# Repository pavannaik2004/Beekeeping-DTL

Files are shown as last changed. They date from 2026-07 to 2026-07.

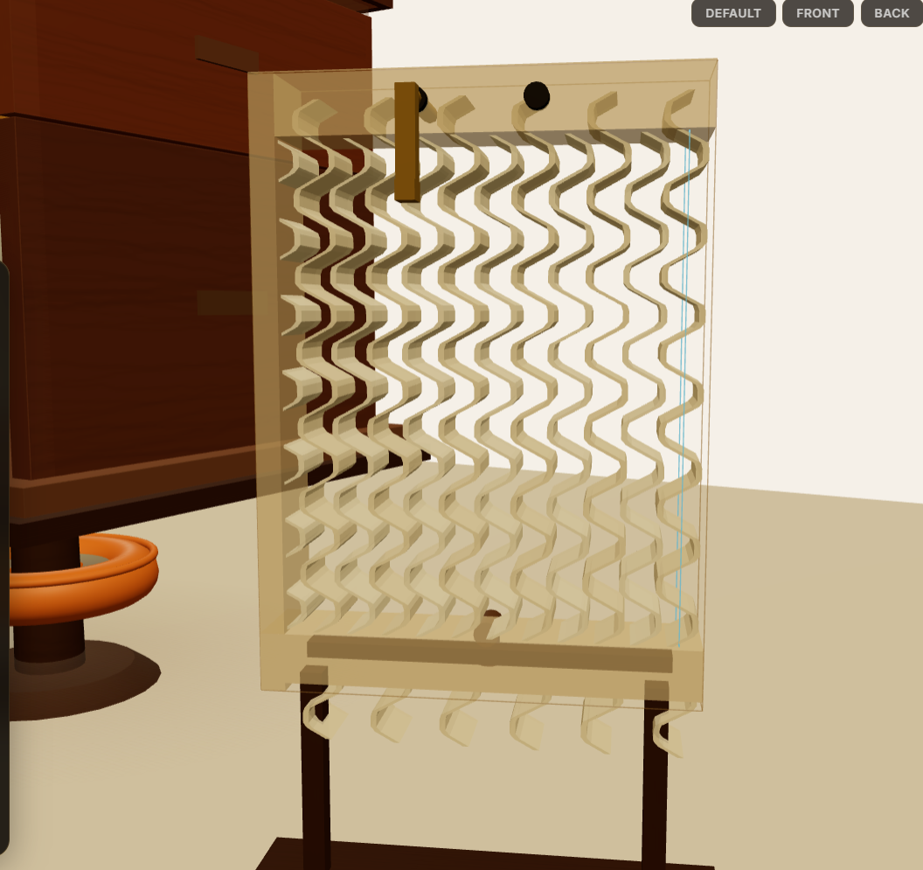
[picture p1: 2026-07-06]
04-prototype/prototype-versions/detailed_flowframe.png

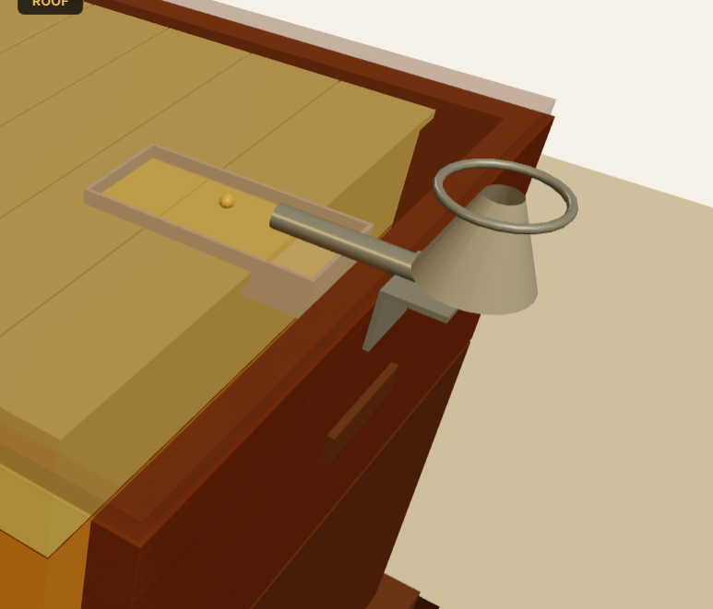
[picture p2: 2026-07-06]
04-prototype/prototype-versions/feeder.png

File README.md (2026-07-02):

# Beekeeping-DTL: Efficient Beekeeping and Hive Box

## File Structure

```text
Directory structure:
└── pavannaik2004-beekeeping-dtl/
    ├── README.md
    ├── 01-empathy/
    │   ├── 00-overview.md
    │   ├── 01-research/
    │   │   ├── context-notes.md
    │   │   ├── field-observation.md
    │   │   ├── FLOW-HIVE-–-A-NOVEL-TECHNOLOGY-FOR-BEEKEEPING.pdf
    │   │   ├── important-links.md
    │   │   ├── is.1515.1998.pdf
    │   │   ├── Promoting Scientific Beekeeping For Livelihood Security.pdf
    │   │   ├── Scientific-Bee-Keeping-Report-2.pdf
    │   │   ├── secondary-research.md
    │   │   └── Media/
    │   │       ├── Bee box.png
    │   │       ├── Beecamp.jpg
    │   │       ├── capped_frame.jpg
    │   │       ├── extra_hive_above_box.jpg
    │   │       ├── frame_after_harvesting.jpg
    │   │       ├── Life-cycle-honeybee.webp
    │   │       ├── pavan_holding_frame.jpg
    │   │       ├── sizes-honeybee-worker-queen-drone.webp
    │   │       └── sumanth_holding_frame.jpg
    │   ├── 02-survey/
    │   │   ├── bee-questionnaire.md
    │   │   ├── survey-design-notes.md
    │   │   └── responses/
    │   │       └── Beekeeping Practices and Challenges Survey  (Responses).xlsx
    │   ├── 03-interviews/
    │   │   ├── interview-index.md
    │   │   ├── Akshay Kedla/
    │   │   │   ├── Akshay Kedla Interview.mp3
    │   │   │   ├── README.md
    │   │   │   ├── summary.md
    │   │   │   └── transcript.md
    │   │   ├── Dhruv Bhat/
    │   │   │   ├── Dhruva Bhat Researcher.mp3
    │   │   │   ├── README.md
    │   │   │   ├── summary.md
    │   │   │   ├── transcript.md
    │   │   │   └── Media/
    │   │   │       ├── WhatsApp Image 2026-05-13 at 16.46.42 (1).jpeg
    │   │   │       ├── WhatsApp Image 2026-05-13 at 16.46.42 (2).jpeg
    │   │   │       ├── WhatsApp Image 2026-05-13 at 16.46.42.jpeg
    │   │   │       ├── WhatsApp Image 2026-05-13 at 16.46.43.jpeg
    │   │   │       ├── WhatsApp Image 2026-05-13 at 16.47.08.jpeg
    │   │   │       ├── WhatsApp Image 2026-05-13 at 16.47.23.jpeg
    │   │   │       ├── WhatsApp Image 2026-05-13 at 16.50.06.jpeg
    │   │   │       └── WhatsApp Video 2026-05-13 at 16.49.09.mp4
    │   │   ├── Harsha Hegde/
    │   │   │   ├── Harsha Hegde.mp3
    │   │   │   ├── README.md
    │   │   │   ├── summary.md
    │   │   │   └── transcript.md
    │   │   ├── Manjunath Hegde/
    │   │   │   ├── Manjunath.aac
    │   │   │   ├── README.md
    │   │   │   ├── summery.md
    │   │   │   └── transcription.md
    │   │   ├── Pavan/
    │   │   │   ├── Pramath Interview.mp3
    │   │   │   ├── README.md
    │   │   │   ├── summary.md
    │   │   │   └── transcription.md
    │   │   ├── Sushanth Hegde/
    │   │   │   ├── README.md
    │   │   │   ├── summary.md
    │   │   │   ├── Sushant Hegde Interview.mp3
    │   │   │   └── transcript.md
    │   │   └── Ullas Naik/
    │   │       ├── README.md
    │   │       ├── summary.md
    │   │       ├── transcript.md
    │   │       ├── Ullas Naik Interaction.mp3
    │   │       └── Media/
    │   │           ├── 1.mp4
    │   │           ├── 2.mp4
    │   │           ├── 3.mp4
    │   │           └── 4.mp4
    │   ├── 04-empathy-map/
    │   │   └── README.md
    │   ├── 05-personas/
    │   │   └── README.md
    │   ├── 06-pain-points/
    │   │   └── README.md
    │   ├── 07-quotes/
    │   │   └── README.md
    │   └── 08-insights/
    │       └── README.md
    ├── 02-define/
    │   ├── 00-overview.md
    │   ├── 01-affinity-mapping/
    │   │   └── README.md
    │   ├── 02-pain-point-analysis.md
    │   ├── 03-need-statements.md
    │   ├── 04-problem-statement.md
    │   ├── 05-how-might-we.md
    │   └── 06-scope-decision.md
    ├── 03-ideate/
    │   ├── README.md
    │   ├── 01-brainstorming/
    │   │   ├── idea-log.md
    │   │   └── README.md
    │   ├── 02-dot-voting/
    │   │   ├── README.md
    │   │   └── voting-results.md
    │   ├── 03-concept-notes/
    │   │   ├── README.md
    │   │   └── top-concepts.md
    │   ├── 04-selection-matrix/
    │   │   ├── evaluation.md
    │   │   └── README.md
    │   ├── 05-storyboarding/
    │   │   ├── README.md
    │   │   └── assets/
    │   └── 06-innovation-and-impact/
    │       ├── 01-innovation-details.md
    │       ├── 02-social-impact.md
    │       ├── 03-biological-impact.md
    │       ├── 04-economic-impact.md
    │       └── README.md
    ├── 04-prototype/
    │   ├── prototype-versions/
    │   │   └── README.md
    │   ├── sketches/
    │   │   └── README.md
    │   └── wireframes/
    │       └── README.md
    └── 05-test/
        ├── feedback/
        │   └── README.md
        ├── iterations/
        │   └── README.md
        └── test-plan/
            └── README.md
```

## Project Overview

This is a Design Thinking Lab (DTL) project for the MCA 2nd semester focused on designing an efficient beekeeping solution and hive box system.

**Project Name:** Efficient Beekeeping and Hive Box
**Team:** Pavan Mohan Naik, Sumanth Bhaskar Hegde, Pramath Prakash Hegde
**Guide:** Dr. Mohan Aradhya

## Project Structure

* Beekeeping-DTL: Efficient Beekeeping and Hive Box
  * File Structure
  * Project Overview
  * Project Structure
    * 01-empathy/
    * 02-define/
    * 03-ideate/
    * 04-prototype/
    * 05-test/
  * Getting Started
  * Contributing

The repository is organized following the Design Thinking methodology with the following phases:

### 01-empathy/

Research and user discovery artifacts:

- **01-research/**: Field observation records, context/secondary research notes, guide PDFs, and media assets.
- **02-survey/**: Bee questionnaire design, survey notes, and responses spreadsheet.
- **03-interviews/**: Transcripts, audio files (`.mp3`/`.aac`), summaries, and media attachments for individual interviewees (Akshay Kedla, Dhruv Bhat, Harsha Hegde, Manjunath Hegde, Pavan, Sushanth Hegde, Ullas Naik).
- **04-empathy-map/**, **05-personas/**, **06-pain-points/**, **07-quotes/**, **08-insights/**: Phase outcomes and artifacts synthesized from research.

### 02-define/

Synthesis artifacts and problem definition:

- **01-affinity-mapping/**: Grouping of research observations.
- **02-pain-point-analysis.md**: Detailed breakdown of user challenges.
- **03-need-statements.md**: User-focused requirements.
- **04-problem-statement.md**: The core problem to be solved.
- **05-how-might-we.md**: Framed opportunity areas.
- **06-scope-decision.md**: Focus areas for the next phases.

### 03-ideate/

Ideation phase deliverables:

- **01-brainstorming/**: Idea log and general ideation notes.
- **02-dot-voting/**: Voting results to prioritize ideas.
- **03-concept-notes/**: Top concept details.
- **04-selection-matrix/**: Evaluation criteria and final concept selection.
- **05-storyboarding/**: Visual storytelling of the user journey before and after the proposed design.
- **06-innovation-and-impact/**: Detailed analysis of the project's innovation and its projected social, biological, and economic impact.

### 04-prototype/

Prototype development artifacts:

- **sketches/**: Hand-drawn concepts and design ideas.
- **wireframes/**: Digital layout/interaction wireframes.
- **prototype-versions/**: Physical and digital prototype iterations.

### 05-test/

Testing and validation phase:

- **test-plan/**: Protocols and setup for user testing.
- **feedback/**: Collected feedback from user tests.
- **iterations/**: Design changes based on feedback.

## Getting Started

To explore this project:

1. Navigate through the phase folders in order (01 → 05)
2. Start with the `00-overview.md` files in each phase
3. Review the research artifacts and synthesis documents

## Contributing

This is an academic project. For questions or contributions, please contact the team members.

---

_Last Updated: May 2026_

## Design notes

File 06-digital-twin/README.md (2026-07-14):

# 06 — Digital Twin (1:1 Parametric CAD Model)

A precise, manufacturable **1:1 digital twin** of the upgraded beehive shown in
the Three.js visualiser on the `gh-pages` branch. Every dimension comes from
that model's "ISI STANDARD DIMENSIONS" block; on top of it this twin adds the
engineering layer that makes the design physically buildable: rabbet joinery,
fit tolerances, a real slotted queen excluder, and a working flow-frame cam
mechanism.

Built with [build123d](https://build123d.readthedocs.io/) (Python + the
OpenCascade BREP kernel — the same math commercial CAD uses).

## Quick start

```bash
cd 06-digital-twin
python -m venv .venv
.venv/Scripts/pip install -r requirements.txt   # (Linux/mac: .venv/bin/pip)

.venv/Scripts/python -m hive_twin.checks     # engineering verification
.venv/Scripts/python -m hive_twin.export     # STEP + STL + GLB + manifest
.venv/Scripts/python -m hive_twin.drawings   # dimensioned SVG sheets
.venv/Scripts/python -m hive_twin.bom        # BOM.md / BOM.csv

python -m http.server 8000                   # then open
# http://localhost:8000/viewer/              # interactive 3D viewer
```

## Deliverables

| Where | What |
|---|---|
| `exports/step/` | Per-part STEP + `beehive_assembly.step` (FreeCAD/Fusion/SolidWorks) |
| `exports/stl/` | Per-part STL, all watertight and 3D-printable |
| `exports/glb/hive.glb` | Merged model with named parts + materials (for the viewer) |
| `exports/drawings/` | A3 drawing sheet per unique part: front/side/top hidden-line views, overall dims, title block |
| `exports/BOM.md` / `.csv` | Bill of materials incl. consumables |
| `viewer/index.html` | Interactive digital twin: slide both shutters, turn the flow key, exploded view, per-module toggles, hover part info. Pose via URL too, e.g. `?ex=1&sl=150&hv=1` |
| `screenshots/` | Rendered verification shots (closed pose, exploded harvest pose) |

## Structure

- `hive_twin/params.py` — **single source of truth**: every dimension (mm),
  tolerance and stack height. Change a value, re-run export: the whole model,
  drawings and BOM update.
- `hive_twin/parts/*.py` — one module per component (49 solids total).
- `hive_twin/assembly.py` — part registry, materials, viewer actions.
- `hive_twin/checks.py` — verification: Y-stack, fits, and boolean
  interference checks across 34 mating part pairs.

## The engineering layer (what makes it "work")

- **Coordinates**: X width, Y height (up), Z depth (front +Z) — identical to
  the Three.js scene. Units mm.
- **Tolerances**: sliding fits 0.4 mm total (shutters, flow key), static fits
  0.2 mm (acrylic panes, box tongues), telescoping roof 2 mm/side.
- **Joinery**: boxes are four interlocking boards with 10×10 mm rabbets —
  printable or cuttable, self-squaring.
- **Bee space** (9 mm) respected at the frame rests and top-bar gap.
- **Queen excluder**: 4.2 mm slots between 2 mm bars — workers pass, the
  queen cannot (real apiary spec).
- **Flow-frame cam**: the key blade is 3.2 mm lying flat and 13.2 mm upright;
  turning it 90° inside the frame lifts the moving cell-columns exactly
  (13.2 − 3.2)/2 = **5.0 mm**, opening the cells so honey drains:
  columns → frame trough → front spout → external manifold → tap → hose → jar.
- **Windows**: 5 mm acrylic in a rebated MDF ring; 3 mm shutter riding in
  3.4 mm grooves with 150 mm travel and a stop pin.

## Documented deviations from the Three.js visualiser

The visualiser is a *visual* model; three of its choices are physically
impossible and were engineered around (everything else matches 1:1):

1. **Manifold** — shown *inside* the super, 6 mm below its floor (where the
   queen excluder is). The twin mounts it externally on the front wall, fed
   by a Ø7 spout from each frame.
2. **Tap/hose/jar at Z = 277.5** — would pass through the landing board.
   Moved to Z = 300 (75 mm → 97.5 mm in front of the box).
3. **Telescoping roof** — drawn floating above the cover. The twin's roof
   board rests on the inner cover with the rim skirting 10 mm down around
   the super (that is what "telescoping" means).

If 3D-printing at 1:1 note the biggest boards exceed a 250 mm bed and must be
sectioned (or print at reduced scale: every STL is watertight so slicers can
scale freely). For a real hive, build the wooden parts from the drawings and
print only the flow frames, excluder, feeder and plumbing.

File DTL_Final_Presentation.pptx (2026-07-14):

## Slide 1

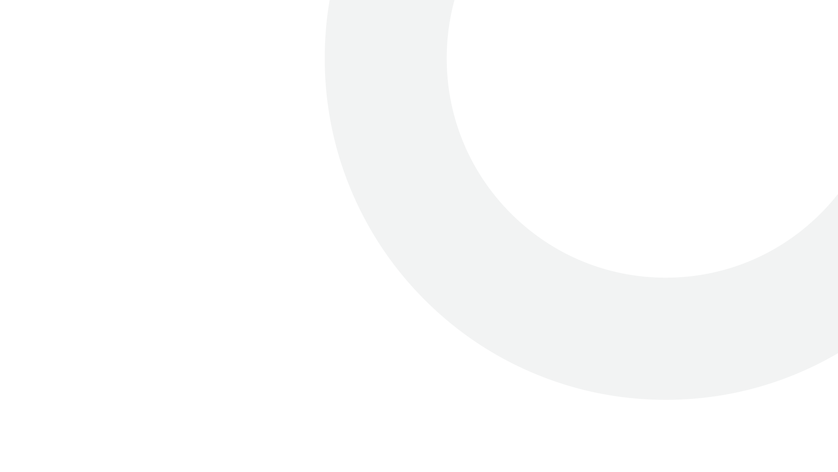
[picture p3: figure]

Department of Master of Computer Applications

Design Thinking

Efficient Beekeeping and Hive Box

Pavan Mohan Naik
Sumanth Bhaskar Hegde
Pramath Prakash Hegde

Under the Guidance
of
Dr. Mohan Aradhya
Assistant Professor

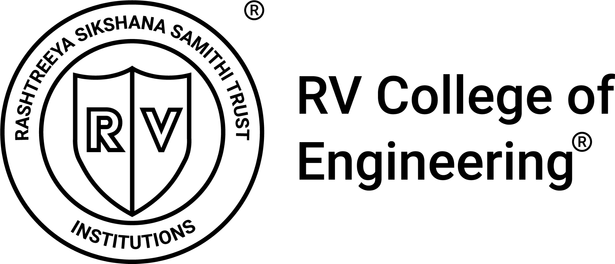
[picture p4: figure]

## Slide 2

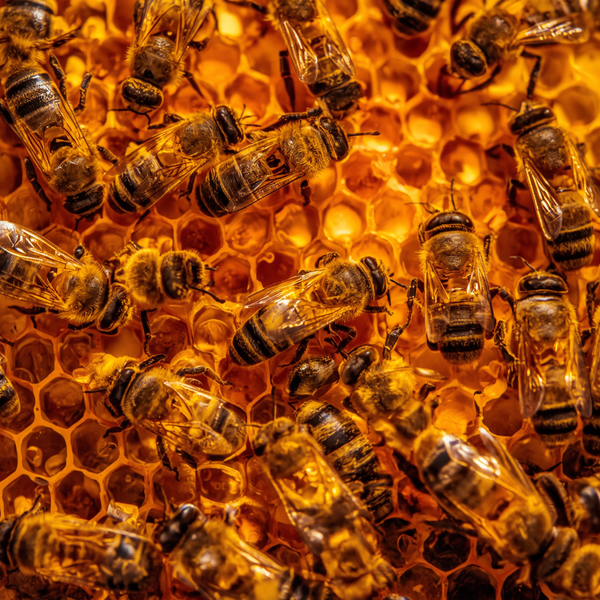
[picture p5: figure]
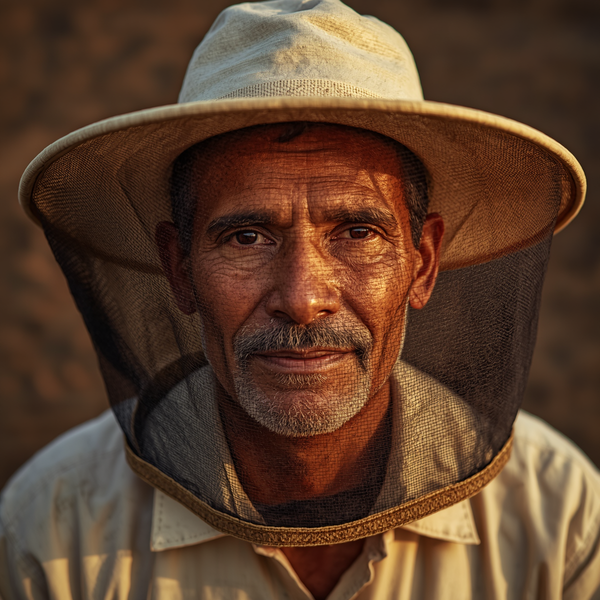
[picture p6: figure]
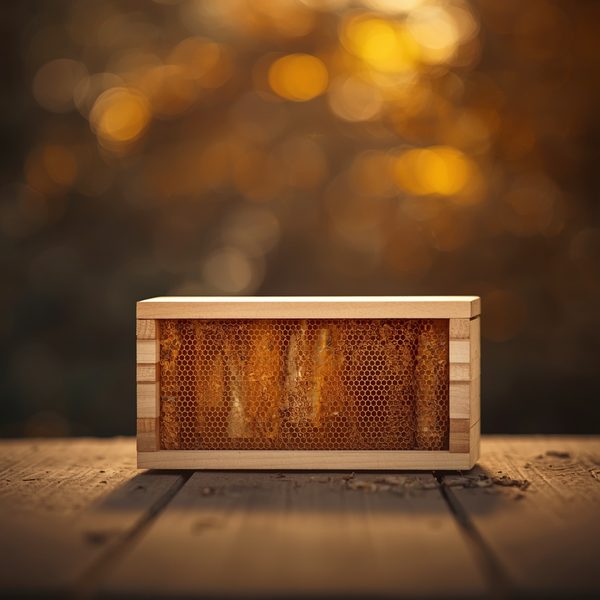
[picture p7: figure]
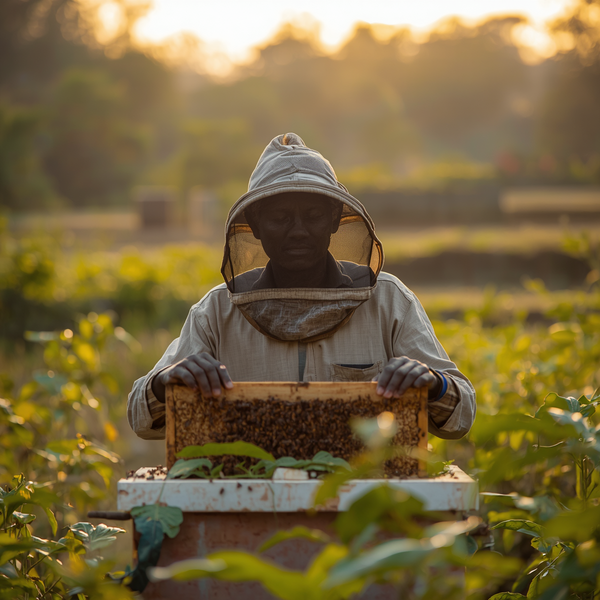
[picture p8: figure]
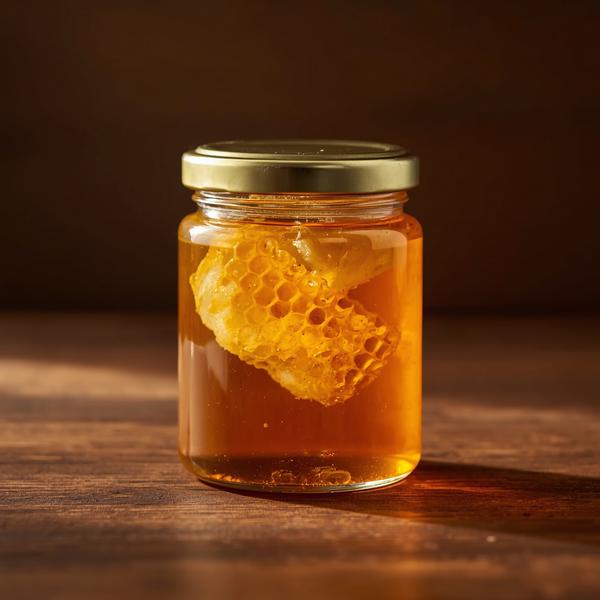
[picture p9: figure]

Final Project Presentation · Design Thinking Lab

The Complete
Design Journey

Efficient Beekeeping & Hive Box — Empathize to Field-Ready Prototype

B

BeeHive

Design Lab

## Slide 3

OUR APPROACH

The Design Thinking Process

Empathize

Interviews, surveys & field research with beekeepers, societies and beginners.

1

Define

Synthesised the pains into one sharp, user-centred problem statement.

2

Ideate

Brainstormed and scored concepts against user needs and a ₹4,000 budget.

3

Prototype

Interactive 3D visualiser plus a low-cost physical retrofit build.

4

Test

Usability, thermal and bee-behaviour validation with real beekeepers.

5

›

›

›

›

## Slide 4

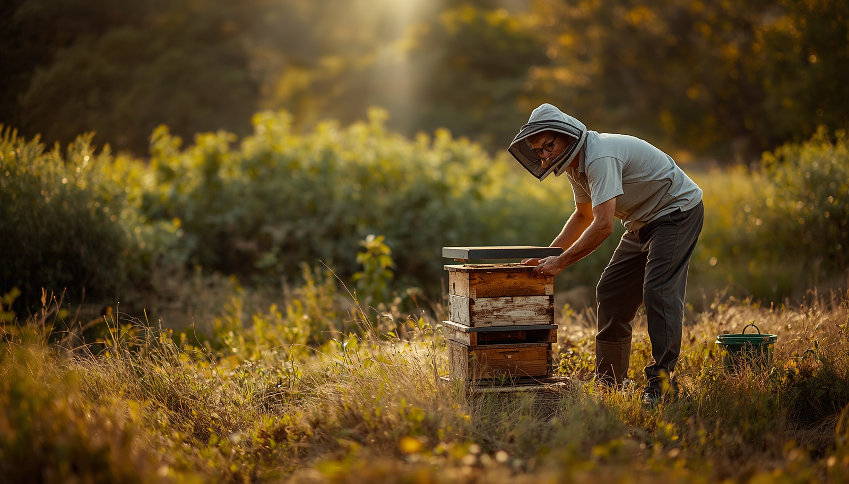
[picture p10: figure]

The Core Problem

Small-scale farmers fear bee stings and lack hive expertise.
Traditional hive inspection is risky, disruptive, and costly.
Need safer, simpler, low-cost inspection and maintenance solutions.
Budget constraint: Upgrade cost must stay under ₹4,000.

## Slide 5

01 · EMPATHIZE

Research & Key Insights

How We Researched

• 7 in-depth interviews — beekeepers, bee societies & beginners
• Google Form survey of beekeepers and honey consumers
• Field observation and a hands-on bee training camp
• Secondary research — Flow Hive, ISI standards, literature

What We Learned

• Fear of stings is the biggest barrier to adoption
• Inspection is reactive — hives opened only when a problem shows
• Climate & pests drive colony loss; monsoon is hardest
• Knowledge gap — most rely on informal, inconsistent learning
• Farmers want affordability over expensive automation

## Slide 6

02 · DEFINE

Point of View & Problem Definition

“Small-scale Indian beekeepers need a safer, affordable and easy-to-use hive-management solution — because current methods are too risky, costly and technically demanding for everyday use.”

ROOT CAUSE

Small farmers are underserved by beekeeping technology — existing solutions don’t match their budget, climate, skill level or scale.

Safer inspection

Affordable & local

Simple — no expert needed

Works through monsoon

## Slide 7

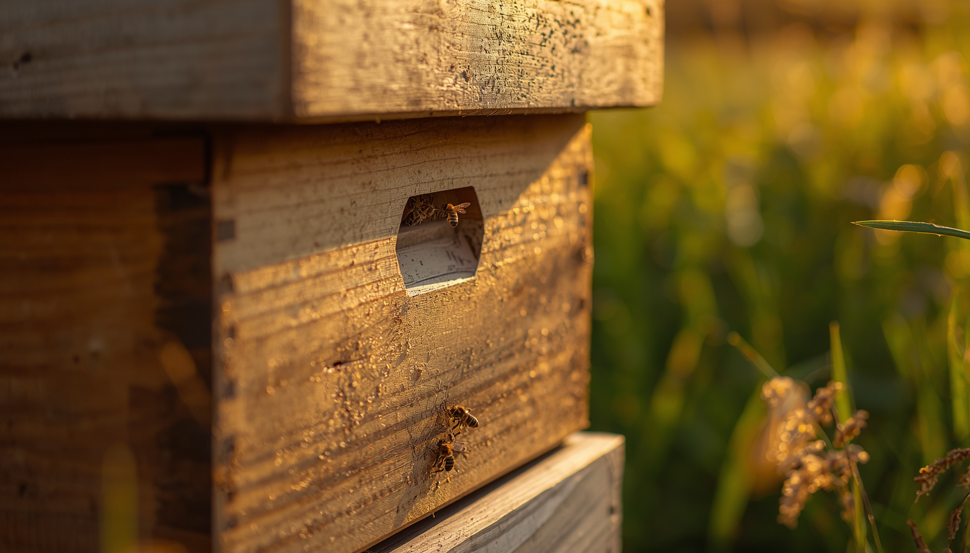
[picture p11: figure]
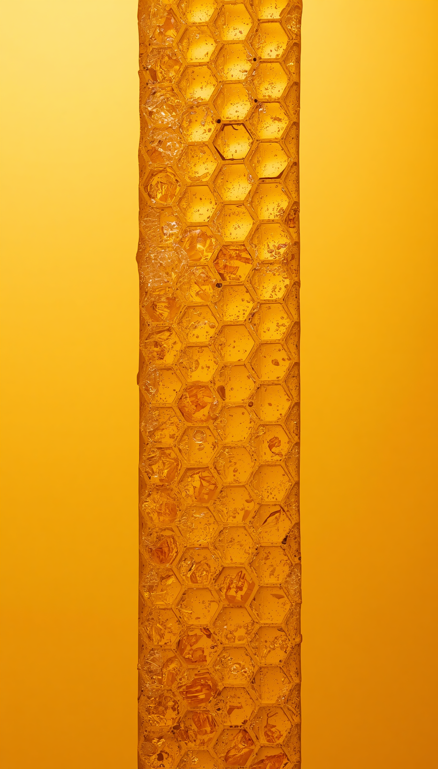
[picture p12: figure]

IDEATE — FROM 3 "HOW MIGHT WE"s
TO THE TOP 6 CONCEPTS

  1. Acrylic Window with sliding cover for visual hive checks
  2. External Sugar Syrup Feeder with outside refill funnel
  3. Clip-On Modular Super for hive expansion
  4. Auto-Harvest Flow System with tilt pipe for honey extraction
  5. Donut Water Ring for pest protection
  6. Internal Thermal Insulation using coir/jute

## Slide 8

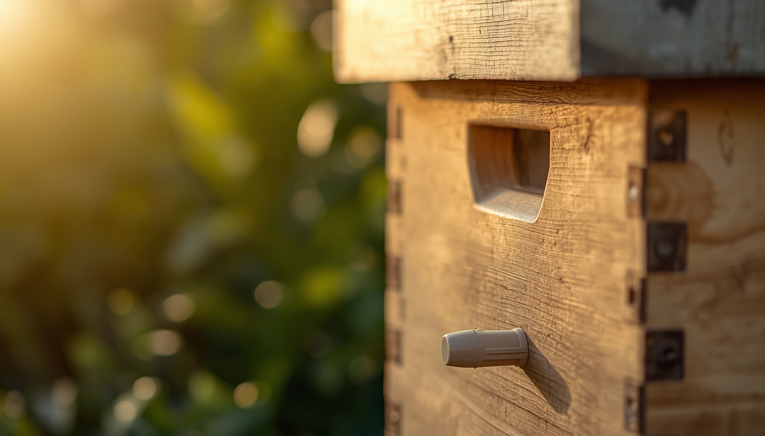
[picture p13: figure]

THE WINNING SOLUTION: SAFE INSPECTION & FEEDING UPGRADE

Acrylic window allows visual hive inspection without opening the lid
External feeder enables syrup feeding without hive disruption
Retrofit design fits existing ₹2,500 wooden boxes affordably
Non-disruptive design preserves hive micro-climate and reduces sting risk

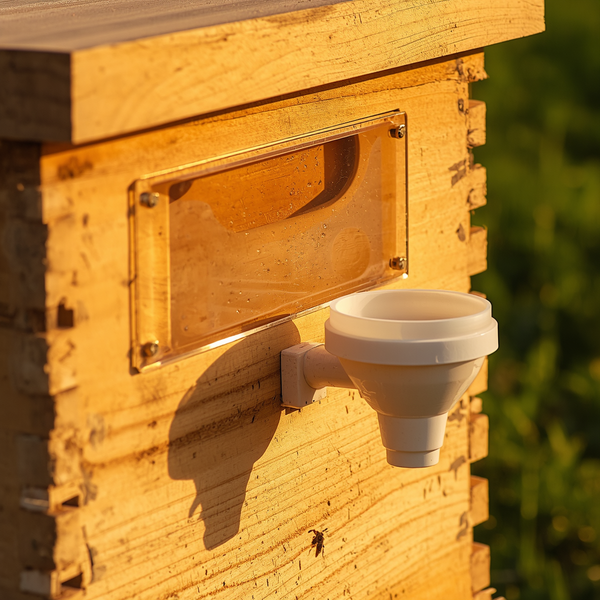
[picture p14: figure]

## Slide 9

04 · PROTOTYPE

Design Realised — Safe Inspection & Feeding Upgrade

Full hive — ISI standard

• Dual acrylic inspection windows (left + back) with sliding shutters
• External top feeder — refill syrup without opening the hive
• Flow-harvest frames: pipe → tap → ground collection jar

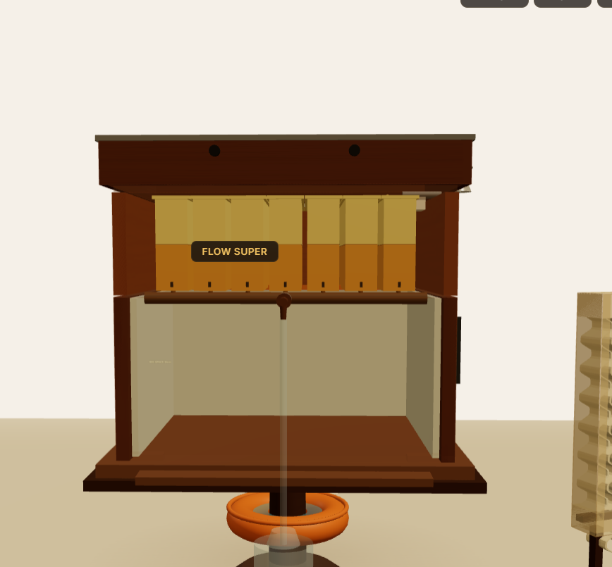
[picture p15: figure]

Acrylic inspection window

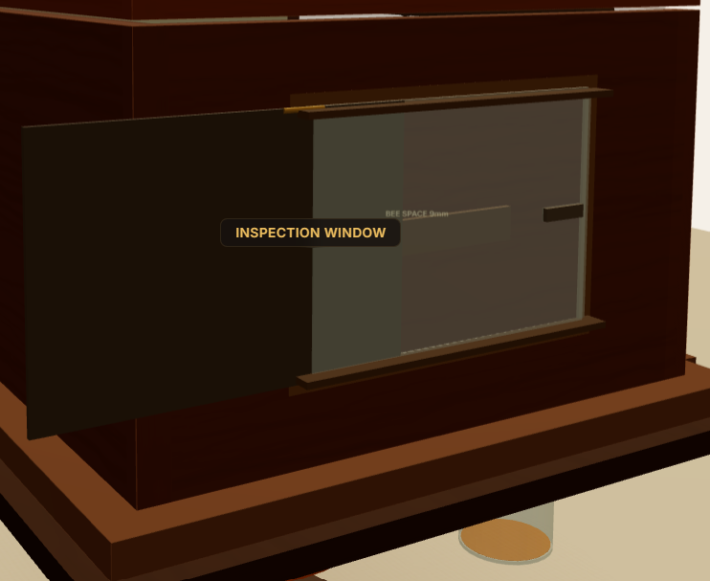
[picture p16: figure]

External top feeder

• 10 mm XPS internal insulation holds the 35°C brood micro-climate
• Donut water-ring ant moat that doubles as a bee waterer
• Retrofits any standard ₹2,500 wooden box — no structural change


KEY UPGRADES

Interactive 3D visualiser built procedurally with Three.js (no external models).

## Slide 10

04 · PROTOTYPE

Build Roadmap & Iterations

v0.1

Paper / cardboard mock-up

Validate layout & dimensions

v0.2

Foam-board + real acrylic

Bee space, light leak, thermal

v0.3

Full working unit (budget)

End-to-end beekeeper test

v1.0

Standard tier — ₹4,000

Final field validation

Complete

In progress

Planned

Planned

ALREADY IMPROVED THROUGH ITERATION

Added a mandatory 6.35 mm bee-space verification step · changed the feeder float from synthetic foam to food-safe coir fibre.

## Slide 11

05 · TEST

Usability Validation Plan

1

Installation usability — fit the module with hand tools, no hive opening

CRITICAL SUCCESS CRITERIA

• Zero hive openings during inspection & feeding
• Brood temperature held at 33–36°C for 5 days
• Zero bee drowning in the feeder trough
• Installation under 45 minutes with hand tools
• Beekeeper satisfaction ≥ 4 / 5

2

Inspection window — answer 5 colony-status questions vs. ground truth

3

Feeder usability — refill reservoir, confirm bees feeding, zero drowning

4

Thermal & structural — 5-day brood-temperature and condensation log

5

Bee behaviour — guarding, fanning and propolis-sealing observation

Participants: 3+ beekeepers across 2 test sites — partnering with the Karnataka Beekeepers’ Co-operative, Bengaluru.

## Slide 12

Anticipated Impact

Operational Efficiency

97.5% Reduction in Inspection Time Turns a traditional 20-minute, high-prep inspection into a seamless 30-second visual check

Safety & Usability

100% Elimination of Routine Gear Completely eliminates the need to wear heavy, hot protective suits or use smoke for standard visual checks and feeding.

Risk Mitigation

₹2,000 Asset Protection External feeding prevents dry-season starvation, directly saving the farmer the ₹1,500 – ₹2,000 cost of replacing a dead bee colony.

Economic Accessibility

80% Cost Savings vs. Redesign The modular upgrade costs < ₹500, which is an 80% saving compared to forcing farmers to buy a completely new ₹2,500 wooden box.

Biological Productivity

~15-20% Projected Yield Increase Preserving the hive's 35°C internal micro-climate redirects bee energy from temperature regulation back into honey production.

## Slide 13

CONCLUSION

From Insight to a Field-Ready Solution

A design-thinking journey from empathy to engineering: real beekeeper research distilled into one sharp problem, then a sub-₹500 retrofit that turns a risky 20-minute hive inspection into a 30-second visual check.

NEXT STEPS

• Build the v0.2 / v0.3 physical prototype for field trials
• Run the 5-session usability test with rural beekeepers

• Iterate on UV-tint clarity, shutter humidity & propolis sealing
• Explore low-cost distribution through beekeeping co-operatives

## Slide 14

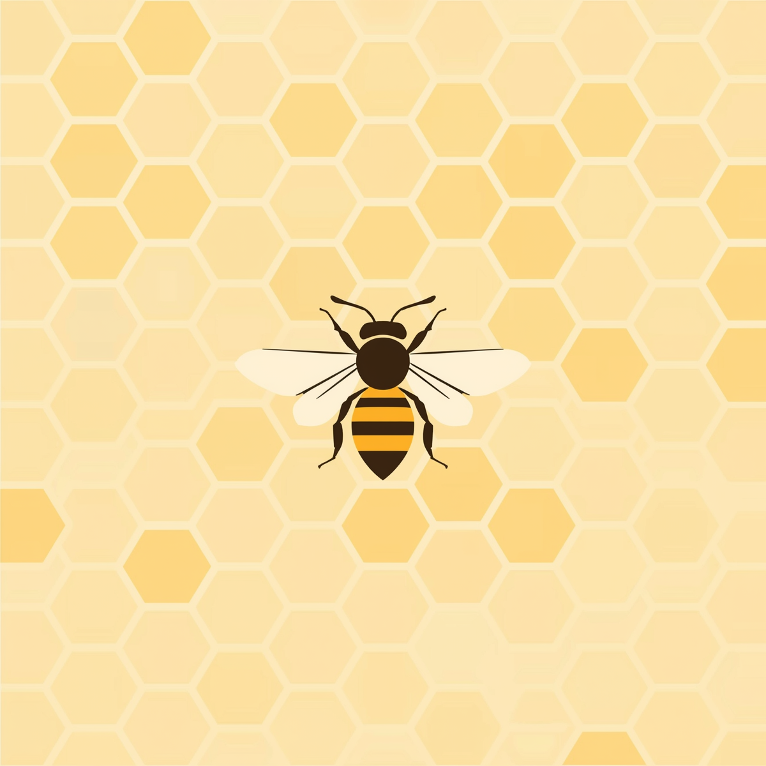
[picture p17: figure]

Thank You

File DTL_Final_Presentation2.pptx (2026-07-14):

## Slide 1


Department of Master of Computer Applications

Design Thinking

Efficient Beekeeping and Hive Box

Pavan Mohan Naik
Sumanth Bhaskar Hegde
Pramath Prakash Hegde

Under the Guidance
of
Dr. Mohan Aradhya
Assistant Professor

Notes: 1.7.2013



‹#›

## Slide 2

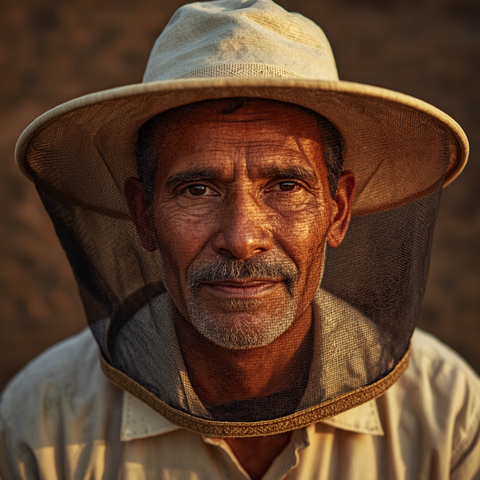
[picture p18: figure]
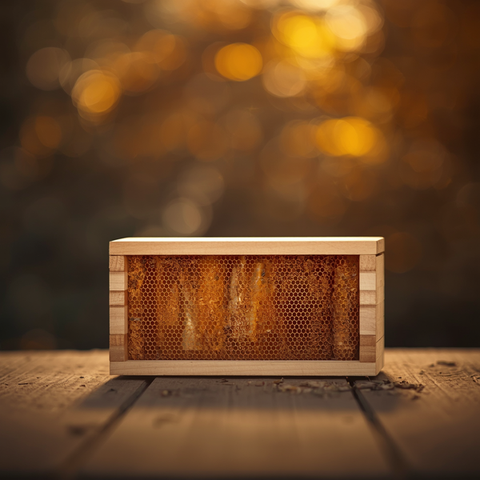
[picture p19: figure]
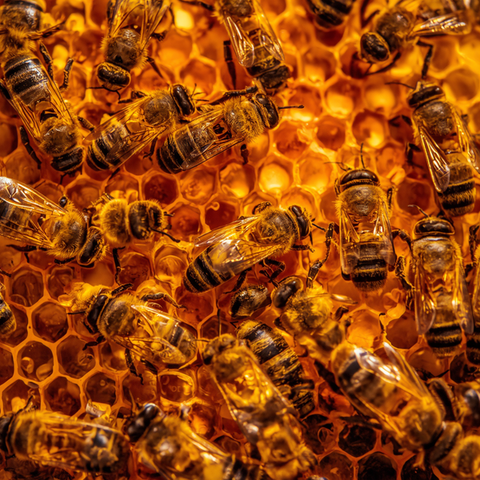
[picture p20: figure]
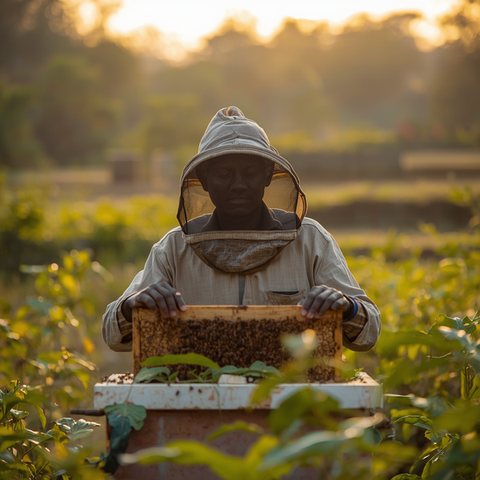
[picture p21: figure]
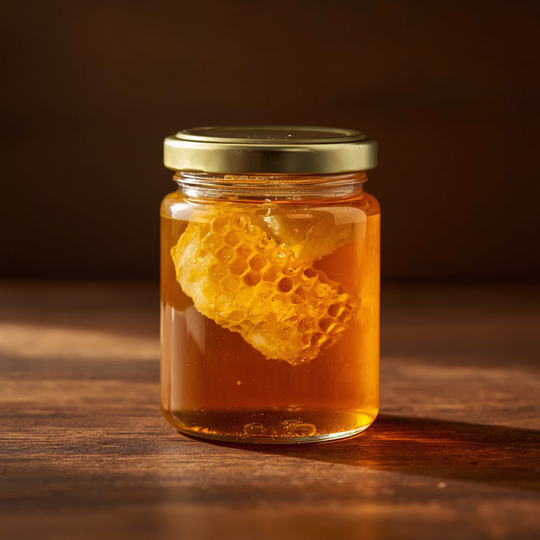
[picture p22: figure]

Final Project Presentation · Design Thinking Lab

The Complete
Design Journey

Efficient Beekeeping & Hive Box Empathize to Field-Ready Prototype

BeeHive

Design Lab

B

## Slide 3

OUR DATA

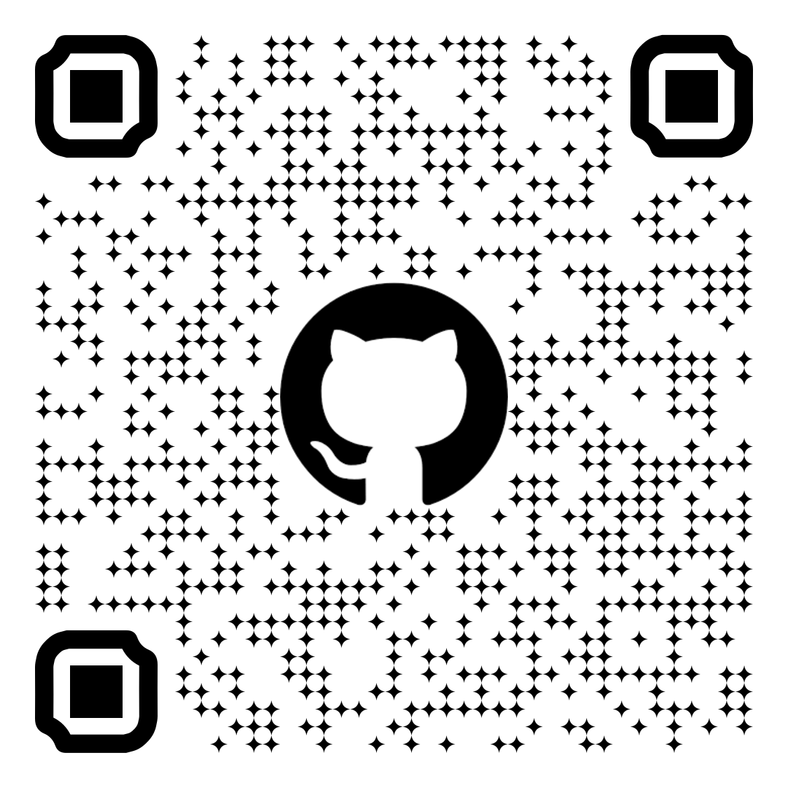
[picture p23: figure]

DOCUMENTATION

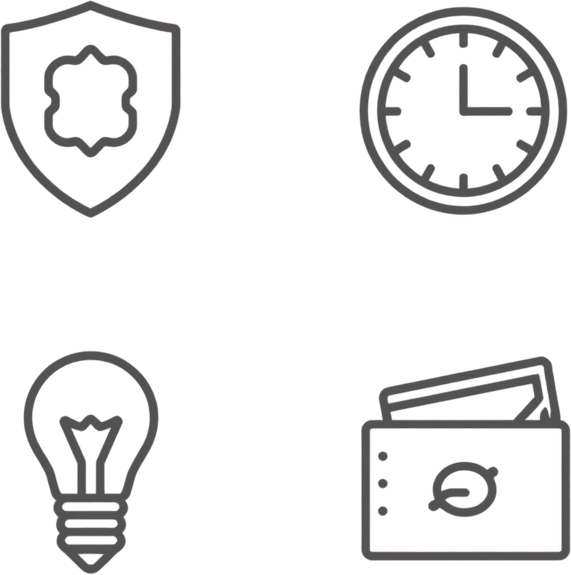
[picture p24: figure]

Well Structured Repo

Contains Raw data and refined Results

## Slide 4

OUR APPROACH

The Design Thinking Process

Empathize

Interviews, surveys & field research with beekeepers, societies and beginners.

1

Define

Synthesised the pains into one sharp, user-centred problem statement.

2

Ideate

Brainstormed and scored concepts against user needs and a ₹4,000 budget.

3

Prototype

Interactive 3D visualiser plus a low-cost physical retrofit build.

4

Test

Usability, thermal and bee-behaviour validation with real beekeepers.

5

›

›

›

›

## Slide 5


The Core Problem

  - Small-scale farmers fear bee stings and lack hive expertise. [Harsha, Sushanth]
  - Traditional hive inspection is risky, disruptive, and costly. [2,3]
  - Need safer, simpler, low-cost inspection and maintenance solutions. [Beekeeper survey]
  - Budget constraint: Upgrade cost must stay under ₹4,000.

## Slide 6

01 · EMPATHIZE

Research & Key Insights

How We Researched

• 7 in-depth interviews — beekeepers, bee societies & beginners
• Google Form survey of beekeepers and honey consumers
• Field observation and a hands-on bee training camp
• Secondary research — Flow Hive, ISI standards, literature [1,4,6]

What We Learned

• Fear of stings is the biggest barrier to adoption [Harsha, Sushanth]
• Inspection is reactive — hives opened only when a problem shows [Manjunath, Sushanth]
• Climate & pests drive colony loss; monsoon is hardest [Beekeeper survey, Dhruv]
• Knowledge gap — most rely on informal, inconsistent learning [Dhruv, Ullas]
• Farmers want affordability over expensive automation [Ullas, Harsha]

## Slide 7

02 · DEFINE

Point of View & Problem Definition

“Small-scale Indian beekeepers need a safer, affordable and easy-to-use hive-management solution , because current methods are too risky, costly and technically demanding for everyday use.”

ROOT CAUSE

Small farmers are underserved by beekeeping technology — existing solutions don’t match their budget, climate, skill level or scale. [2,3,8]

Safer inspection

Affordable & local

Simple — no expert needed

Works through monsoon

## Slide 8

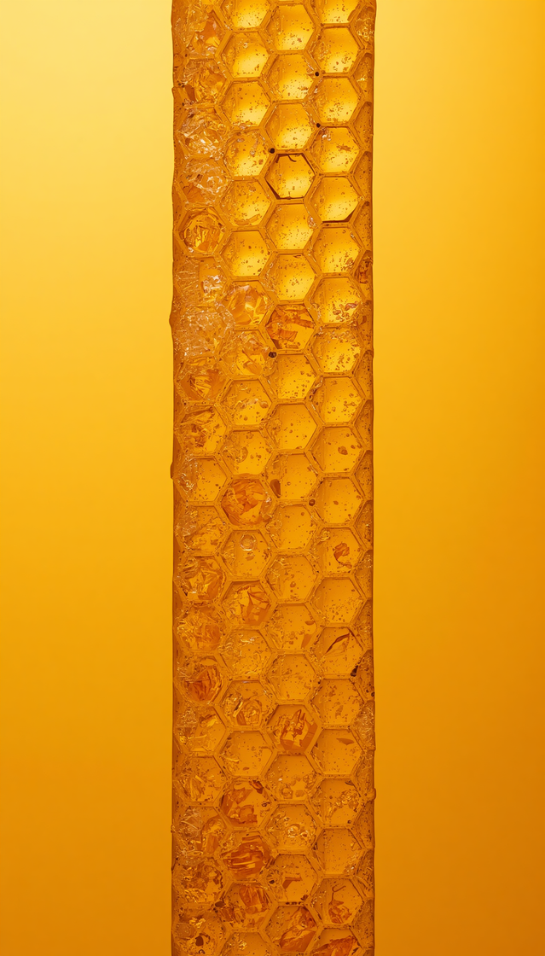
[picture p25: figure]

IDEATE : FROM 3 "HOW MIGHT WE"s
TO THE TOP 6 CONCEPTS

    1. Acrylic Window with sliding cover for visual hive checks
    2. External Sugar Syrup Feeder with outside refill funnel
    3. Clip-On Modular Super for hive expansion
    4. Auto-Harvest Flow System with tilt pipe for honey extraction [4,5]
    5. Donut Water Ring for pest protection
    6. Internal Thermal Insulation using coir/jute

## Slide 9


THE SOLUTION: SAFE INSPECTION & FEEDING UPGRADE

  - Acrylic window allows visual hive inspection without opening the lid
  - External feeder enables syrup feeding without hive disruption
  - Retrofit design fits existing ₹2,500 wooden boxes affordably
  - Non-disruptive design preserves hive micro-climate and reduces sting risk [1]

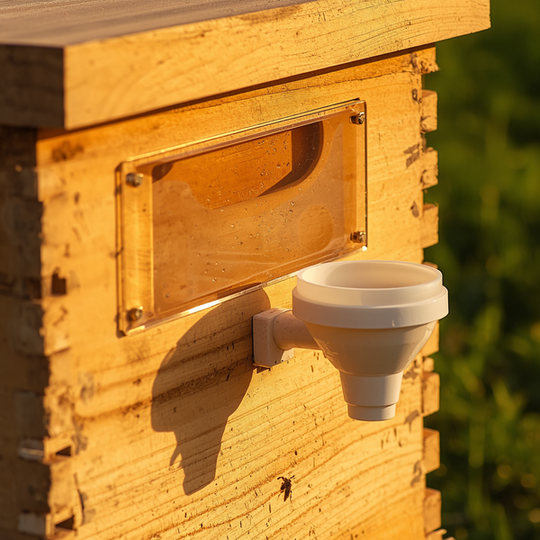
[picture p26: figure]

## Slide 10

04 · PROTOTYPE

Design Realised — Safe Inspection & Feeding Upgrade


Full hive — ISI standard [1]

• Dual acrylic inspection windows (left + back) with sliding shutters
• External top feeder — refill syrup without opening the hive
• Flow-harvest frames: pipe → tap → ground collection jar [4,5]


Acrylic inspection window


External top feeder

• 10 mm XPS internal insulation holds the 35°C brood micro-climate [1]
• Donut water-ring ant moat that doubles as a bee waterer
• Retrofits any standard ₹2,500 wooden box — no structural change

KEY UPGRADES

Interactive 3D visualiser built procedurally with Three.js (no external models).

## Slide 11

05 · TEST

Usability Validation Plan

1

Installation usability — fit the module with hand tools, no hive opening

CRITICAL SUCCESS CRITERIA

• Zero hive openings during inspection & feeding
• Brood temperature held at 33–36°C for 5 days [1]
• Zero bee drowning in the feeder trough
• Installation under 45 minutes with hand tools
• Beekeeper satisfaction ≥ 4 / 5

2

Inspection window — answer 5 colony-status questions vs. ground truth

3

Feeder usability — refill reservoir, confirm bees feeding, zero drowning

4

Thermal & structural — 5-day brood-temperature and condensation log

5

Bee behaviour — guarding, fanning and propolis-sealing observation

Participants: 3+ beekeepers across 2 test sites — partnering with the Karnataka Beekeepers’ Co-operative, Bengaluru.

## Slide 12


Anticipated Impact

Operational Efficiency

97.5% Reduction in Inspection Time Turns a traditional 20-minute, high-prep inspection into a seamless 30-second visual check

Safety & Usability

100% Elimination of Routine Gear Completely eliminates the need to wear heavy, hot protective suits or use smoke for standard visual checks and feeding.

Risk Mitigation

₹2,000 Asset Protection External feeding prevents dry-season starvation, directly saving the farmer the ₹1,500 – ₹2,000 cost of replacing a dead bee colony.

Economic Accessibility

80% Cost Savings vs. Redesign The modular upgrade costs < ₹500, which is an 80% saving compared to forcing farmers to buy a completely new ₹2,500 wooden box.

Biological Productivity

~15-20% Projected Yield Increase Preserving the hive's 35°C internal micro-climate redirects bee energy from temperature regulation back into honey production. [1]

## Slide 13

CONCLUSION

From Insight to a Field-Ready Solution

A design-thinking journey from empathy to engineering: real beekeeper research distilled into one sharp problem, then a sub-₹500 retrofit that turns a risky 20-minute hive inspection into a 30-second visual check.

NEXT STEPS

• Build the v0.2 / v0.3 physical prototype for field trials
• Run the 5-session usability test with rural beekeepers

• Iterate on UV-tint clarity, shutter humidity & propolis sealing
• Explore low-cost distribution through beekeeping co-operatives

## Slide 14

SOURCES

References

1. Bureau of Indian Standards. IS 1515:1998 — Bee Hive (Newton / ISI type): Specification. BIS, New Delhi. (hive dimensions & 9 mm bee-space)
2. Monga, K. & Manocha, A. (2011). Adoption and constraints of beekeeping in District Panchkula (Haryana), India. Livestock Research for Rural Development, 23(5).
3. Gadekar, U. B. (2026). Problems of Bee Farming in Rural Maharashtra: A Case Study of Patgaon Village. Int. J. of Engineering and Management Research, 16(1), 38–45.
4. Flow Hive. Wikipedia — mechanism & caveats of one-tap flow harvesting. en.wikipedia.org/wiki/Flow_Hive

5. Agriallis (2025). Flow Hive – A Novel Technology for Beekeeping. agriallis.com
6. MANAGE. Promoting Scientific Beekeeping for Livelihood Security. National Institute of Agricultural Extension Management. manage.gov.in
7. KVK Delhi. Scientific Bee-Keeping Report. kvkdelhi.org
8. Agriculture.Institute (2025). Current Beekeeping Trends in India: Challenges & Opportunities.

PRIMARY RESEARCH — WHO / WHICH FORM

Interviews — Manjunath Hegde, Sushanth Hegde, Harsha Hegde, Ullas Naik, Akshay Kedla (beekeepers) & Dhruv Bhat (bee researcher). · Surveys — Beekeeper & Consumer Google Forms. · Field observation & bee-training camp.

In-text markers: numbered [n] cite the references above · named tags such as [Harsha, Sushanth] are the interviewees quoted · [Beekeeper survey] / [Consumer survey] are our Google Forms. Prototype visuals are the team’s procedural Three.js renders.

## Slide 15


Thank You

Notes: 1.7.2013



‹#›

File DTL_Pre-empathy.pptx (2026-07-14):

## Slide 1

Department of Master of Computer Applications

Design Thinking

Efficient Beekeeping and Hive Box

Pavan Mohan Naik
Sumanth Bhaskar Hegde
Pramath Prakash Hegde

Under the Guidance
of
Dr. Mohan Aradhya
Assistant Professor

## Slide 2

Contents:

Problem Statement
Stakeholder
Assumptions
Current System
Context
Initial Persona
Empathy Plan

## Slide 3

Problem Statement

Farmers face difficulty in adopting and maintaining beekeeping due to complex, risky, and inefficient traditional methods, leading to low adoption and missed opportunities for additional income and improved crop yield.


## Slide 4

Stakeholders

Primary

  - Farmers
  - Beekeepers

Secondary

  - Agricultural cooperatives
  - Honey buyers / distributors
  - Local markets

  - Consumers
  - Government agriculture departments
  - Environment (pollination impact)

Indirect

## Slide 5

Assumptions

ADDITIONAL INCOME

Farmers seek supplementary revenue streams to improve their livelihoods and financial stability.

PERCEIVED RISK

Beekeeping is seen as difficult and dangerous, creating hesitation among potential adopters.

SIMPLICITY DRIVES ADOPTION

Low-maintenance, simplified systems will significantly increase farmer participation rates.

LACK OF AWARENESS

Limited training and knowledge about beekeeping practices prevents farmers from starting.

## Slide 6

Current System: Traditional Beekeeping

PROCESS STEPS

• Opening the hive manually
• Using smoke to calm bees
• Manual honey extraction
• Wearing full protective gear


PAIN POINTS

• High risk of bee stings
• Time-consuming process
• Colony disturbance stress
• Expertise and training needed

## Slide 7

Context and Importance

Context:
  - Around 75% of global food crops depend (at least partly) on pollination (FAO)
  - Bee pollination can increase crop yields by 20–30%, especially in fruits, vegetables, and oilseeds
  - India is the 8th largest honey producer globally, yet scientific beekeeping adoption among small farmers is still limited
  - Beekeeping can increase farmer income by 15–25% through honey and related products

Constraints:
  - Financial limitations and cost sensitivity among beekeepers
  - Time availability for training and hive maintenance
  - Regulatory frameworks and compliance requirements
  - Limited access to beekeeping technologies and extension services

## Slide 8

Initial Persona (Draft)

Name: Harsha Maani
  - Small-scale farmer (1–2 acres)
  - Wants to increase income
  - Has limited time and resources
  - No prior beekeeping experience
Pain Points:
  - Fear of bees
  - Lack of knowledge
  - Complexity of current systems


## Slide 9

Farmer Interviews & Field Observation

Conduct on-site visits to understand daily farming routines, observe current beekeeping practices, and gather firsthand insights.

Beekeeper Discussions

Interview experienced beekeepers to learn techniques, identify pain points, and understand what makes systems successful.


Empathy Research
Plan

Secondary Research & Analysis

Review existing literature, case studies, and Flow Hive documentation to synthesize insights and validate findings.


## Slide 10

Sample Questions


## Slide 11


Thank You

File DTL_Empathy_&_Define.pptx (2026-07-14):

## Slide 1


Department of Master of Computer Applications

Design Thinking

Efficient Beekeeping and Hive Box

Pavan Mohan Naik
Sumanth Bhaskar Hegde
Pramath Prakash Hegde

Under the Guidance
of
Dr. Mohan Aradhya
Assistant Professor

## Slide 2


Efficient Beekeeping and Hive Box
Empathy & Define Phase


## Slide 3


How We Collected Data

Our research approach combined multiple methods to gather comprehensive insights:
  - In-depth user interviews with beekeepers, bee societies & Beginners
  - Google Form survey for Beekeepers & Consumers
  - Secondary Research , Bee Training Camp


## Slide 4

OUR DATA

DOCUMENTATION


Well Structured Repo

Contains Raw data and refined Results

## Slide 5

User Interviews & Observation Highlights


Infrequent Inspection Due to Effort

Hive inspection feels time-consuming & exhausting → farmers only open hives when a visible problem occurs, not on a schedule.

[INT-Manjunath][INT-Sushanth]

Adoption Hesitation Fear of Stings

Small farmers interested in extra income hesitate to start beekeeping due to fear of bee stings and colony disturbance during hive opening.

[INT-Harsha][INT-Manjunath]

Hive Opening is the Hardest Task

Survey confirms hive inspection is among the most difficult parts of beekeeping opening and checking hives ranks as a top challenge.

[SUR-Beekeepers]

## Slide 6

User Interviews & Observation Highlights

Colony Loss & Pest Exposure

Societies report recurring challenges: colony loss, pest infestations, and pesticide exposure all requiring careful, regular monitoring.

[SUR-Beekeepers]

NO formal
Training

Most interviewees rely on informal learning rather than structured training, which leads to inconsistent practices and low confidence in “doing it right.”

[INT-Dhruv][INT-Ullas]

Consumer Pressure on Hive Health

Consumers strongly prioritise purity, local source, and trust in honey putting direct pressure on beekeepers to maintain healthy hives and honest practices.

[SUR-Consumers]

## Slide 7

Survey Snapshot


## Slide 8

Survey Snapshot

  - Manages 300+ hives at Kadumane Honey Park
  - Needs cost-effective, modular, and eco-friendly solutions
  - Wants better hive health and harvesting efficiency during monsoons
  - Prefers external feeding systems for large-scale use
  - Natural materials over plastic to maintain honey quality


Dhruva Bhat

Bee Researcher

  - Faces climate-related hive loss and low profits
  - Lacks maintenance knowledge and technical support
  - Wants affordable, practical innovations
  - Prefers value-added bee products over expensive automation


Harsha Hegde

Bee Society
Executive Manager

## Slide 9

Survey Snapshot

  - Struggles with extreme heat, pest attacks, and hive disturbance during inspections
  - Finds automated hive systems too expensive for Indian farmers
  - Prefers shaded modular hive boxes
  - Wants transparent inspection windows with protective dark covers


Ullas Naik

BeeKeeper


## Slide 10

Empathy Map: Understanding the Beekeeper

SAYS

  - "Opening the hive disturbs the bees too much"
  - "I only check when something looks wrong"
  - "Monsoon season is the hardest time"


THINKS

  - Fear of bee stings during inspection
  - Worried about colony loss from climate and pests
  - Doubts whether beekeeping is worth the effort

DOES

  - Opens hive only when a visible problem occurs
  - Uses traditional methods passed down informally
  - Avoids frequent inspections to reduce disturbance

FEEL

  - Anxious during hive inspection
  - Frustrated by low profits and high effort
  - Overwhelmed by lack of technical support

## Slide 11

Key User Needs & Pain Points

Pain Points

  - Hive inspection is risky, disruptive, and time-consuming
  - Fear of bee stings discourages regular monitoring
  - Climate change causes colony loss and pest attacks
  - Lack of training and maintenance knowledge
  - Automated solutions are too expensive for small farmers
  - Low profit margins reduce motivation to continue

User Needs

  - Safer and less disruptive way to inspect hives
  - Affordable and locally suitable hive solutions
  - Simple guidance without needing expert support
  - Modular, eco-friendly hive materials
  - Better income through value-added bee products
  - Tools that work through harsh monsoon seasons

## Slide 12

Point of View Statement

Single-Liner

"Small-scale Indian beekeepers need a safer, affordable, and easy-to-use hive management solution because current methods are too risky, costly, and technically demanding for everyday use."

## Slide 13


ROOT CAUSE ANALYSIS

Surface Problem : Beekeepers avoid regular hive inspection
Why? → Inspection is risky, disruptive, and exhausting
Why? → No safe, simple tools for non-invasive monitoring
Why? → Existing solutions are expensive or designed for large-scale commercial use
Why? → Innovation in beekeeping lacks focus on small-scale Indian farmers

ROOT CAUSE

Small farmers are underserved by beekeeping technology solutions don't match their budget, climate, skill level, or scale.

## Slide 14


Problem Definition

"Small-scale Indian beekeepers lack a safe, affordable, and easy-to-use hive inspection method because existing tools are too expensive, too complex, and not suited for local climate and scale leading to colony loss, low income, and poor adoption of beekeeping."

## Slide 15

Key Insights from Empathy & Define Phase


  1. Fear is the Biggest Barrier
  2. Reactive, Not Proactive
  3. Affordability Over Automation
  4. Climate is a Silent Threat
  5. Knowledge Gap is Widespread

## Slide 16

Thank You

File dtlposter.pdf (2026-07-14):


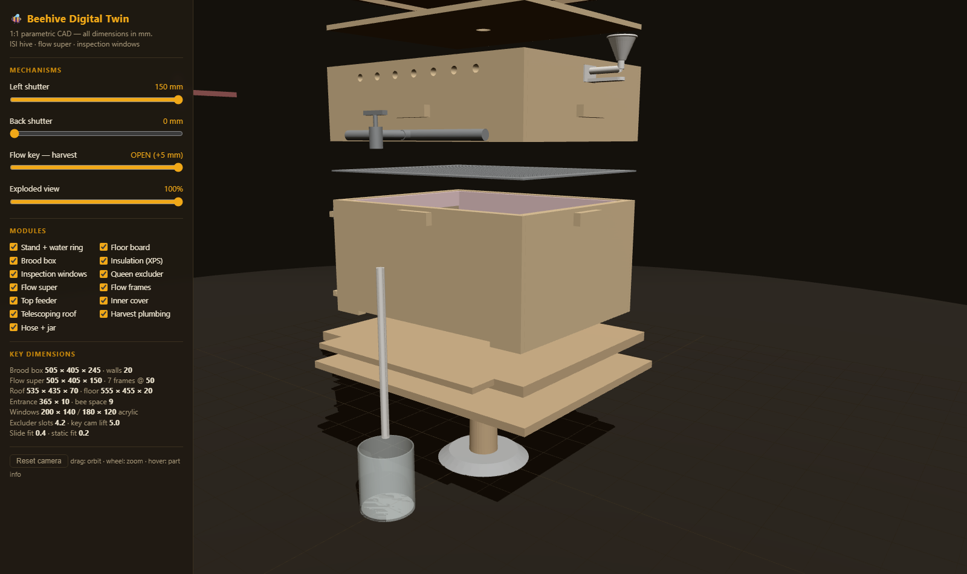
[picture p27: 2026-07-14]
06-digital-twin/screenshots/exploded-harvest.png

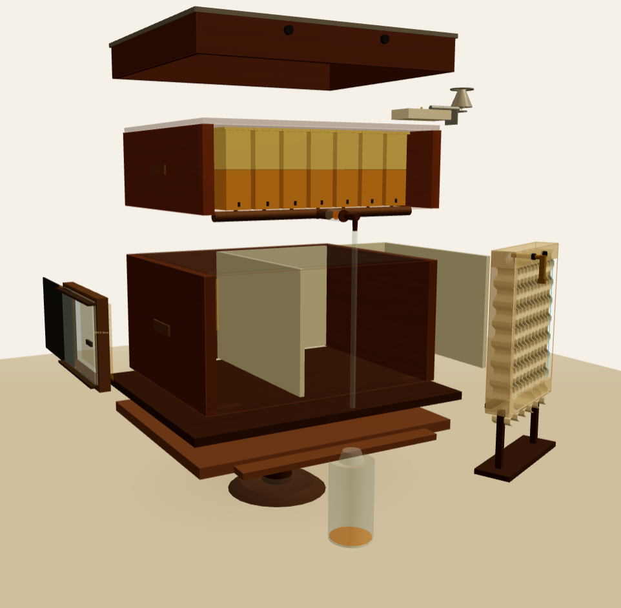
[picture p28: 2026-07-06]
04-prototype/prototype-versions/expanded_view.png

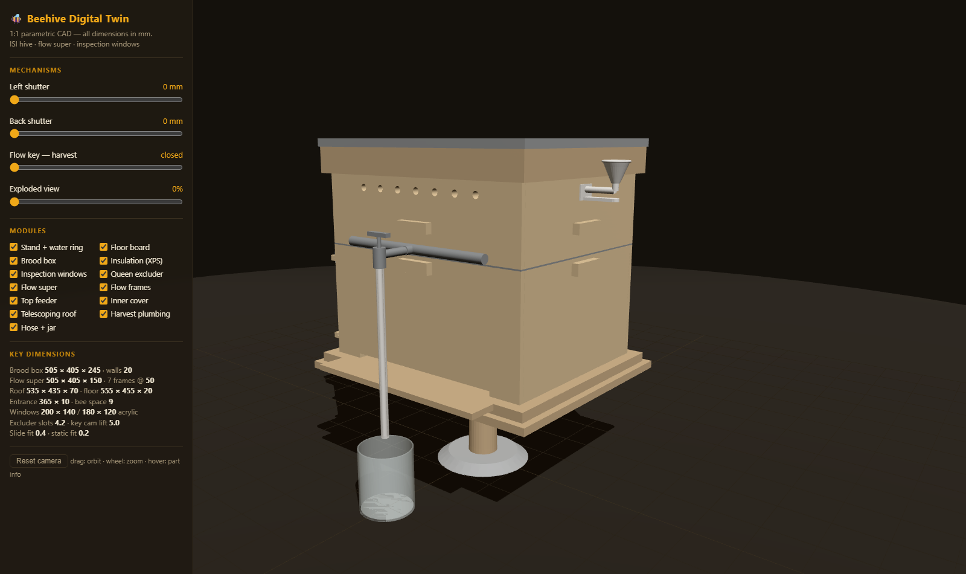
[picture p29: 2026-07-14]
06-digital-twin/screenshots/closed-pose.png

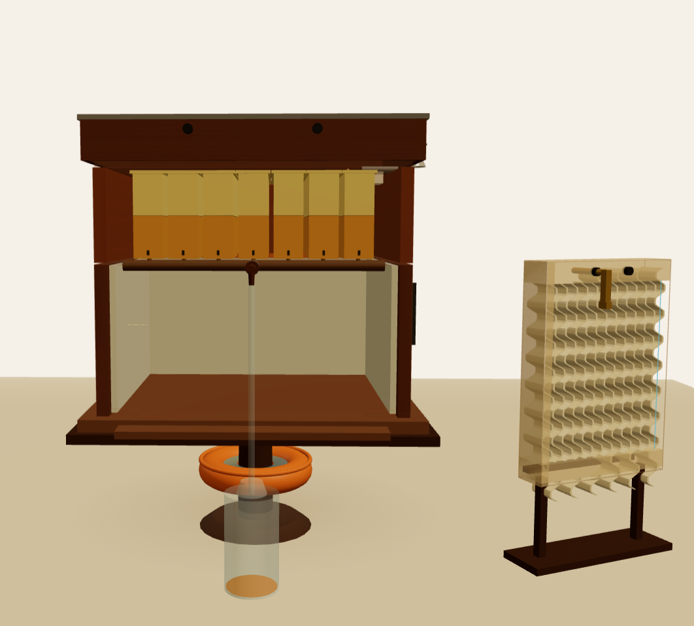
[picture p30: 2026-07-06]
04-prototype/prototype-versions/frontview_hive_and_flowframe.png

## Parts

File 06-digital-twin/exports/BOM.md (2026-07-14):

# Bill of Materials — Beehive Digital Twin (1:1, all mm)

Machined / printed parts: 49 (37 unique). Generated from `hive_twin` parametric model.

| Part | Qty | Material | Module | Bounding box (mm) | Volume (cm³) |
|---|---|---|---|---|---|
| stand_foot | 1 | Concrete / dense wood | Stand + water ring | 210 x 18 x 210 | 487 |
| stand_pole | 1 | Pine wood (roof/floor) | Stand + water ring | 66 x 202 x 66 | 630 |
| stand_platform | 1 | Pine wood (roof/floor) | Stand + water ring | 585 x 16 x 485 | 4540 |
| water_ring | 1 | HDPE (water ring) | Stand + water ring | 138 x 34 x 138 | 252 |
| floor_board | 1 | Pine wood (roof/floor) | Floor board | 555 x 20 x 515 | 5356 |
| brood_wall_front | 1 | Pine wood 20 mm | Brood box | 505 x 245 x 35 | 2382 |
| brood_wall_back | 1 | Pine wood 20 mm | Brood box | 505 x 245 x 35 | 1987 |
| brood_wall_left | 1 | Pine wood 20 mm | Brood box | 35 x 245 x 394 | 1226 |
| brood_wall_right | 1 | Pine wood 20 mm | Brood box | 35 x 245 x 385 | 1865 |
| insulation_left | 1 | XPS foam 10 mm | Insulation (XPS) | 10 x 241 x 365 | 512 |
| insulation_right | 1 | XPS foam 10 mm | Insulation (XPS) | 10 x 241 x 365 | 880 |
| insulation_back | 1 | XPS foam 10 mm | Insulation (XPS) | 445 x 241 x 10 | 779 |
| window_frame_left | 1 | MDF | Inspection windows | 20 x 164 x 224 | 155 |
| acrylic_left | 1 | Clear acrylic 5 mm | Inspection windows | 5 x 150 x 210 | 157 |
| shutter_left | 1 | Plywood shutter 3 mm | Inspection windows | 3 x 174 x 234 | 122 |
| stop_pin_left | 1 | Stainless steel | Inspection windows | 3 x 25 x 3 | 0 |
| window_frame_back | 1 | MDF | Inspection windows | 204 x 144 x 20 | 138 |
| acrylic_back | 1 | Clear acrylic 5 mm | Inspection windows | 190 x 130 x 5 | 123 |
| shutter_back | 1 | Plywood shutter 3 mm | Inspection windows | 214 x 154 x 3 | 99 |
| stop_pin_back | 1 | Stainless steel | Inspection windows | 3 x 25 x 3 | 0 |
| queen_excluder | 1 | Stainless steel | Queen excluder | 505 x 3 x 405 | 287 |
| super_wall_front | 1 | Pine wood 20 mm | Flow super | 505 x 150 x 35 | 1431 |
| super_wall_back | 1 | Pine wood 20 mm | Flow super | 505 x 150 x 35 | 1465 |
| super_wall_left | 1 | Pine wood 20 mm | Flow super | 35 x 150 x 385 | 1150 |
| super_wall_right | 1 | Pine wood 20 mm | Flow super | 35 x 150 x 385 | 1147 |
| ff_fixed | 7 | Food-grade PP | Flow frames | 50 x 140 x 399 | 803 |
| ff_moving | 7 | Food-grade PP (moving) | Flow frames | 46 x 112 x 320 | 466 |
| flow_key | 1 | Painted steel (key) | Flow frames | 80 x 13 x 168 | 14 |
| feeder_funnel | 1 | HDPE / plastic | Top feeder | 120 x 76 x 54 | 27 |
| feeder_tray | 1 | HDPE / plastic | Top feeder | 120 x 45 x 60 | 30 |
| inner_cover | 1 | Pine wood 20 mm | Inner cover | 501 x 10 x 401 | 2002 |
| roof_body | 1 | Pine wood (roof/floor) | Telescoping roof | 535 x 70 x 435 | 3800 |
| roof_tin | 1 | Galvanised tin 2 mm | Telescoping roof | 541 x 17 x 441 | 536 |
| manifold | 1 | Stainless steel | Harvest plumbing | 360 x 20 x 33 | 43 |
| harvest_tap | 1 | Stainless steel | Harvest plumbing | 50 x 66 x 76 | 24 |
| harvest_hose | 1 | Food-grade silicone | Hose + jar | 16 x 336 x 16 | 41 |
| collection_jar | 1 | Glass | Hose + jar | 110 x 130 x 110 | 157 |

## Consumables / hardware

| Item | Qty | Material | Used for | Size |
|---|---|---|---|---|
| wood screws SS 4x40 | 1 | Stainless steel | box corners, cleats, rails | ~60 pcs |
| silicone sealant (food grade) | 1 | Silicone | window acrylic + shutter seal beads | 1 tube |
| frame spacer blocks | 2 | Pine wood | fill 57.5 mm gap each side of the 7 frames | 55 x 20 x 385 |
| exterior paint / linseed oil | 1 | - | weather protection, outside faces only | 0.5 L |
| union coupling 1/2 inch | 1 | Stainless steel | manifold stub to tap pipe | - |

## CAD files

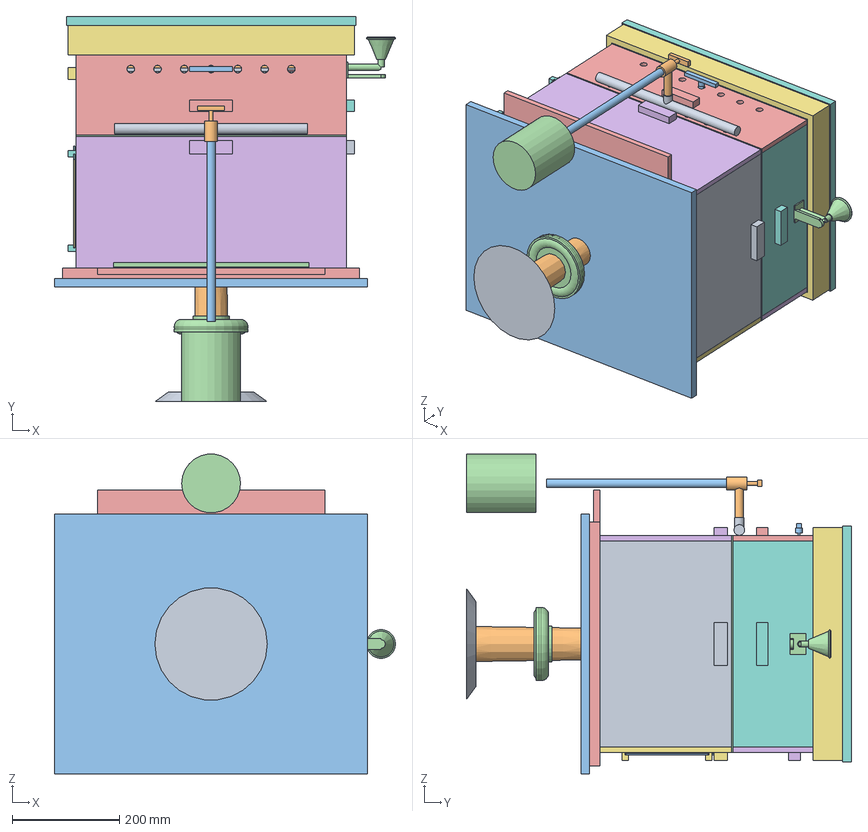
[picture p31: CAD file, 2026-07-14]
06-digital-twin/exports/step/beehive_assembly.step
637.0 x 720.0 x 597.1 mm
stand_foot
stand_pole
stand_platform
water_ring
floor_board
brood_wall_front
brood_wall_back
brood_wall_left
brood_wall_right
insulation_left
insulation_right
insulation_back
window_frame_left
acrylic_left
shutter_left
stop_pin_left
window_frame_back
acrylic_back
shutter_back
stop_pin_back
queen_excluder
super_wall_front
super_wall_back
super_wall_left
super_wall_right
ff0_fixed
ff0_moving
ff1_fixed
ff1_moving
ff2_fixed
ff2_moving
ff3_fixed
ff3_moving
ff4_fixed
ff4_moving
ff5_fixed
ff5_moving
ff6_fixed
ff6_moving
flow_key
feeder_funnel
feeder_tray
inner_cover
roof_body
roof_tin
manifold
harvest_tap
harvest_hose
collection_jar

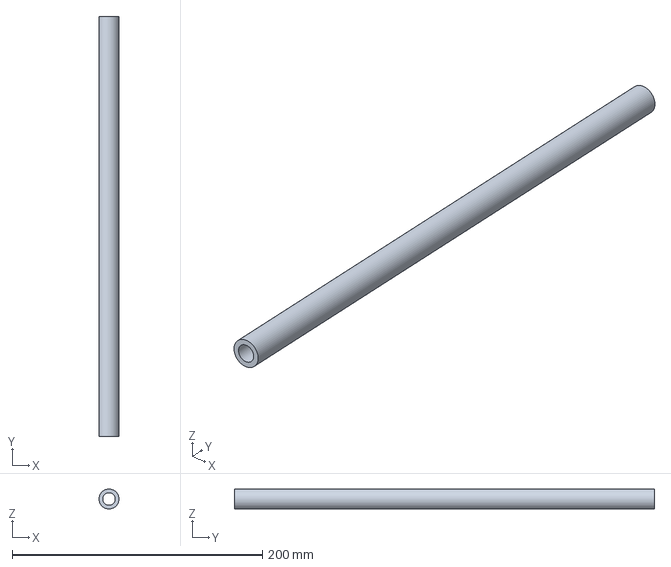
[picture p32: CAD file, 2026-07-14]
06-digital-twin/exports/step/harvest_hose.step
16.0 x 336.0 x 16.0 mm

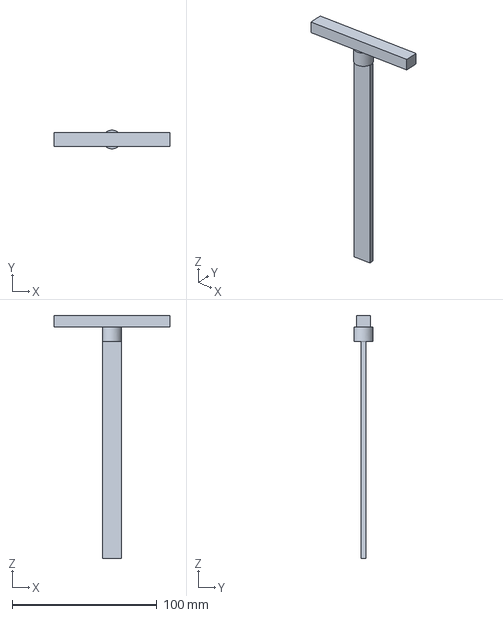
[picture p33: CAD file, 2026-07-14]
06-digital-twin/exports/step/flow_key.step
80.0 x 13.0 x 168.0 mm

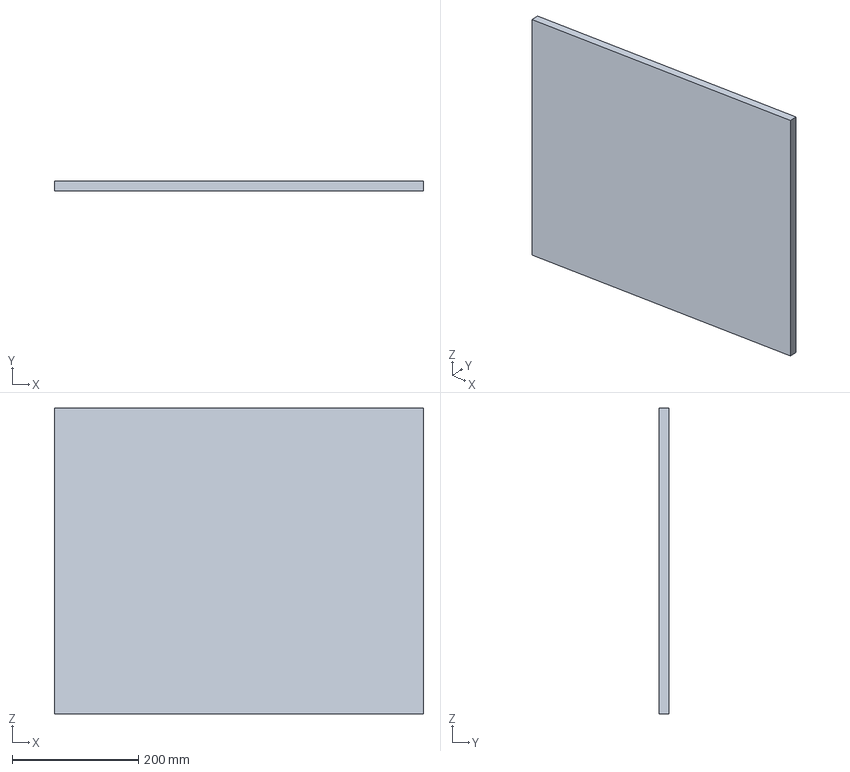
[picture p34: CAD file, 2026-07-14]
06-digital-twin/exports/step/stand_platform.step
585.0 x 16.0 x 485.0 mm

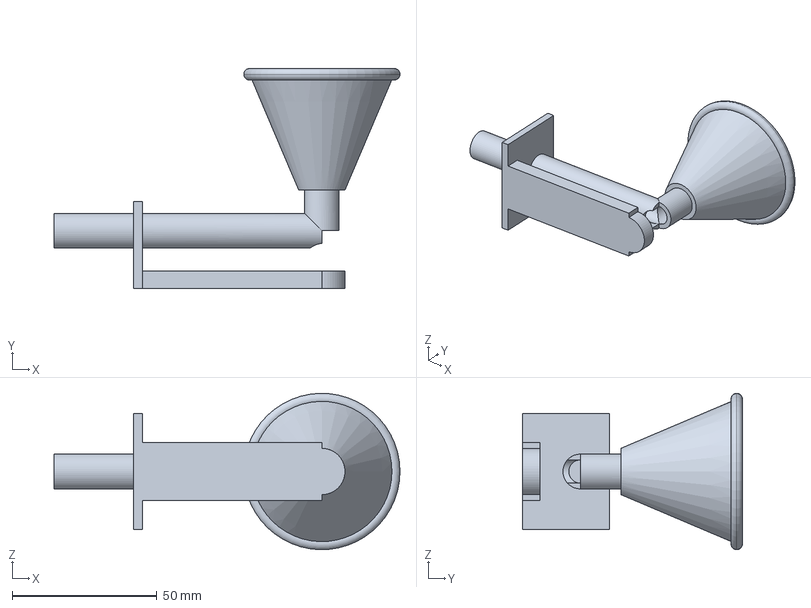
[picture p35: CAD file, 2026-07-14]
06-digital-twin/exports/step/feeder_funnel.step
119.5 x 76.0 x 54.0 mm

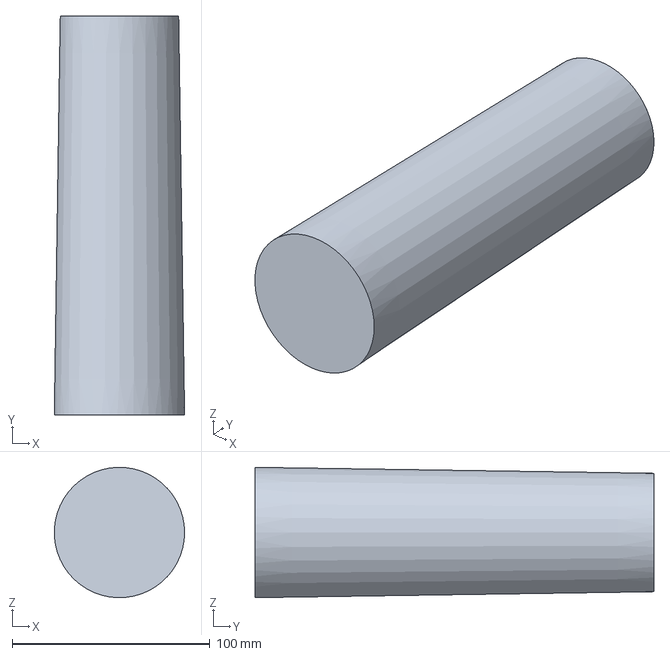
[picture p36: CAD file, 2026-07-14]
06-digital-twin/exports/step/stand_pole.step
65.9 x 202.0 x 66.0 mm

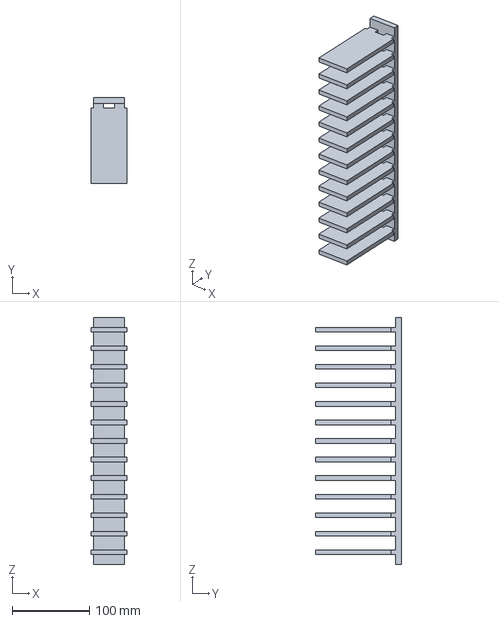
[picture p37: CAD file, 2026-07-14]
06-digital-twin/exports/step/ff5_moving.step
46.0 x 112.0 x 320.0 mm

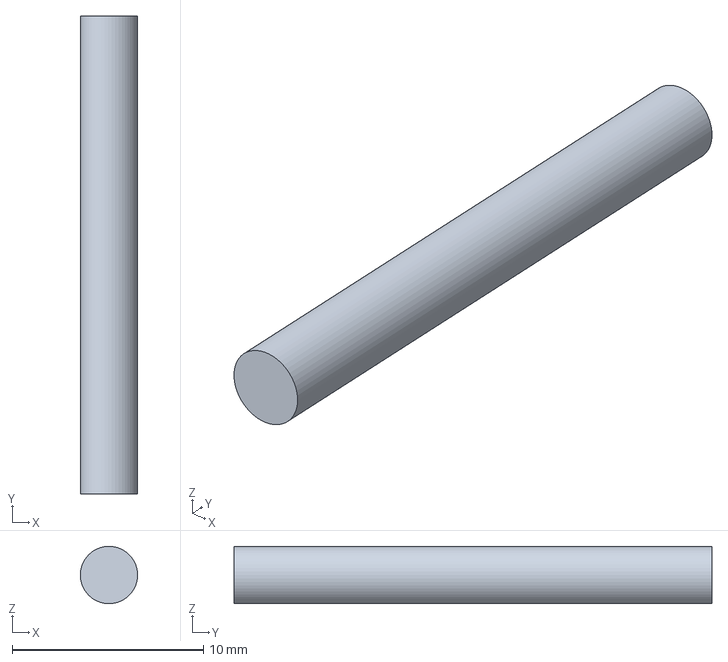
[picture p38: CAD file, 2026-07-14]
06-digital-twin/exports/step/stop_pin_back.step
3.00 x 25.0 x 3.00 mm

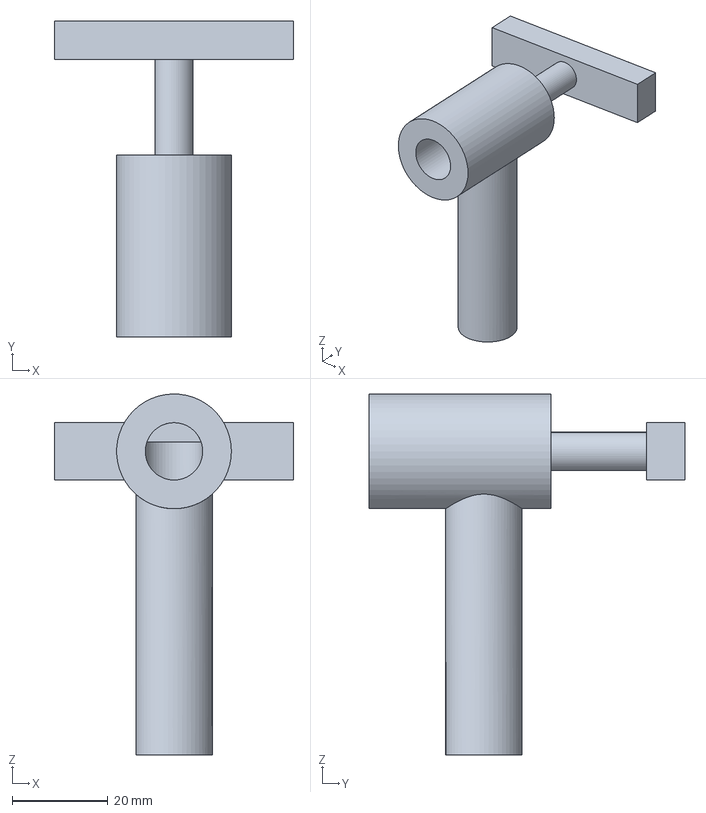
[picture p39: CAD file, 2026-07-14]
06-digital-twin/exports/step/harvest_tap.step
50.0 x 66.0 x 75.5 mm

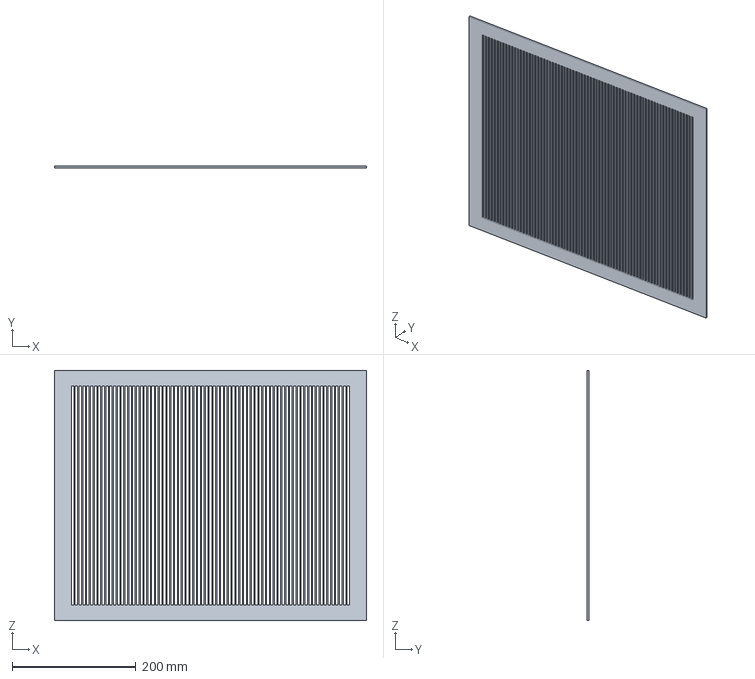
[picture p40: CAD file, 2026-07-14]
06-digital-twin/exports/step/queen_excluder.step
505.0 x 3.00 x 405.0 mm

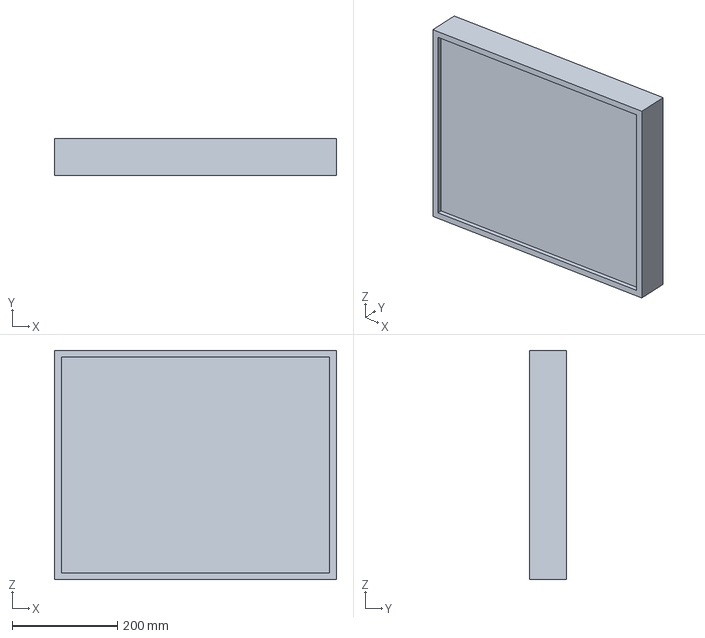
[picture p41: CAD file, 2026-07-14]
06-digital-twin/exports/step/roof_body.step
535.0 x 70.0 x 435.0 mm

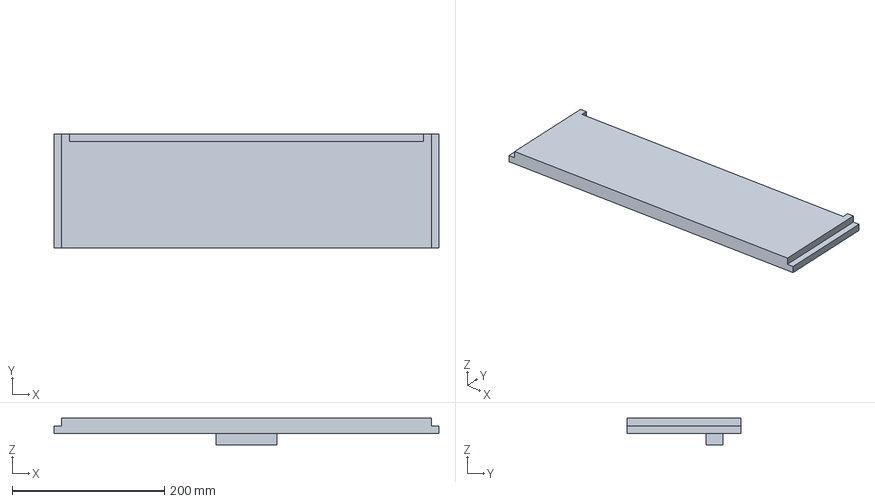
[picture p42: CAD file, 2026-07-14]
06-digital-twin/exports/step/super_wall_back.step
505.0 x 150.0 x 35.0 mm

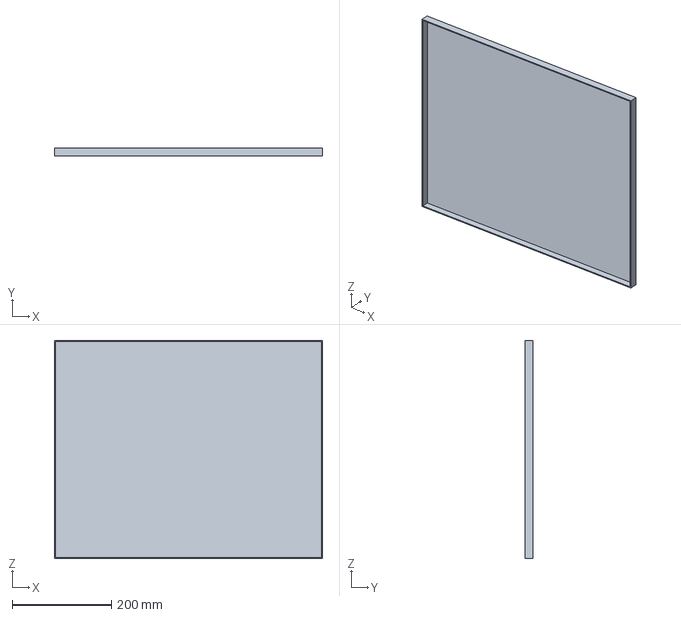
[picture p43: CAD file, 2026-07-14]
06-digital-twin/exports/step/roof_tin.step
541.0 x 17.0 x 441.0 mm

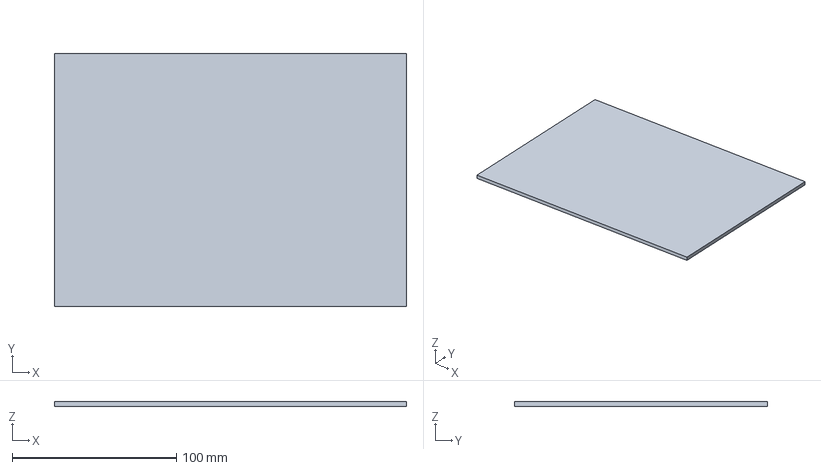
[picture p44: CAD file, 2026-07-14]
06-digital-twin/exports/step/shutter_back.step
214.0 x 154.0 x 3.00 mm

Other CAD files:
06-digital-twin/exports/step/super_wall_right.step
06-digital-twin/exports/step/super_wall_front.step
06-digital-twin/exports/step/collection_jar.step
06-digital-twin/exports/step/acrylic_left.step
06-digital-twin/exports/step/acrylic_back.step
06-digital-twin/exports/step/brood_wall_back.step
06-digital-twin/exports/step/brood_wall_front.step
06-digital-twin/exports/step/brood_wall_left.step
06-digital-twin/exports/step/brood_wall_right.step
06-digital-twin/exports/step/feeder_tray.step
06-digital-twin/exports/step/ff0_fixed.step
06-digital-twin/exports/step/ff0_moving.step
06-digital-twin/exports/step/ff1_fixed.step
06-digital-twin/exports/step/ff1_moving.step
06-digital-twin/exports/step/ff2_fixed.step
06-digital-twin/exports/step/ff2_moving.step
06-digital-twin/exports/step/ff3_fixed.step
06-digital-twin/exports/step/ff3_moving.step
06-digital-twin/exports/step/ff4_fixed.step
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
